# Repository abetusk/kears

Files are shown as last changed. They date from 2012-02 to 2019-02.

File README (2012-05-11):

Must have m4 installed, must have avr-as, avr-ld, avr-objcopy and avrdude.
ATTiny13 programed with ladyada's USBTinyISP (http://www.ladyada.net/make/usbtinyisp/)

To compile kears.asm:

./cmp.sh kears.asm

To program:

./program_avr.sh kears.ihex

If you have any comments or questions, send email to 'abetusk' at 'gmail' dot 'com'.

kears.asm should be functioning now, though I still need to play around
with the different PWM lengths for each state.  I would also like
to play around with adding more states (the "distracted" states)
so that's to be added.

The 'cmp.sh' script is doing the following:
m4 demo.S > demo.asm
avr-as -mmcu=attiny13 -o demo.o demo.asm
avr-ld -o demo.elf demo.o
avr-objcopy --output-target=ihex demo.elf demo.ihex
avrdude -c usbtiny -p t13 -U flash:w:demo.ihex

NOTES:

assumes attiny13 set to internal oscillator at 9.6 MHz

fuse high bits (e.g. fuseh.hex):
:01000000FF00
:00000001FF

fuse low bits (e.g. fusel.hex):
:010000007A85
:00000001FF

to program fuses:
sudo avrdude -c usbtiny -p t13 -U lfuse:w:0x7a:m
sudo avrdude -c usbtiny -p t13 -U hfuse:w:0xff:m
I think...

a note on timing:
we're assuming the attiny13 has been set to an internal
oscillator of 9.6 MHz
we've set up the timer0 overflow to increment once per
clock cycle, which means it should overflow once 
every 256 instructions.
so, 9,600,000 instructions / second
256 instructions / fire
-> 37,500 timer0 fires / second

dammit, can never remember:
Mega  10^6
milli 10^{-3}
micro 10^{-6}

the hxt900 (http://www.servodatabase.com/servo/hextronik/hxt900),
or compatible, servo wants a 450-2450 \mu s (microsecond) 
pulse width with a 20 ms (millisecond) pulse cycle

so, if we wanted to set up a counter in the timer0 overflow
to be on for x microseconds and cycle every y milliseconds

x 10^{-6} = ( X fires ) / ( 37,500 fires / second )
-> X = x * 37,500 / 10^6
-> Y = y * 37,500 / 10^3

for y = 20 milliseconds   -> Y     = 750      fires
for x = 450 microseconds  -> X_min = 16.875   fires
for x = 2450 microseconds -> X_max = 91.875   fires

and of course we have 8bit registers, so if we wanted
to count to 750, we need two registers with the
high bits being 2 and the low bits being 238
( ( 2*2^8 + 238 ) = 750 ).
This is where the values for HPW and LPW come from.
LLEFTC through RRIGHTC simarly come from choosing
values in the range of X_min and X_max.

I've chosen about DEBOUNCEH and DEBOUNCEL to be 
1/10th of a second (100 ms, what we generally 
believe to be 'instantaneous' as humans)
(14*256 + 166) = 3750 fires -> 1/10 second

I've chosen the button timer (how long you need
to press the button before it changes state)
to be .35 of a second.  I might want to decrease
this time a bit because it's noticeably slow.

NOTE (2):

The current working source is the 'kears.asm'.  
I originally programmed this in C but ran into 
size constraints with the ATtiny13 and had to 
switch over to assembly.  I have provided a 
previous version of the source, 'kears.c', in 
case anyone wants to play around with it or 
look at it.  The 'kears.c' should compile and 
work fine, just like the 'kears.asm', version, 
but without the extra 'wink' function (i.e. 
only two preset motions, the 'surprised' and 
'sad/angry' motions are available).

To compile kears.c:

fionna@Ooo:~$ ./cmp.sh

To program:

fionna@Ooo:~$ ./program_avr.sh kears.hex

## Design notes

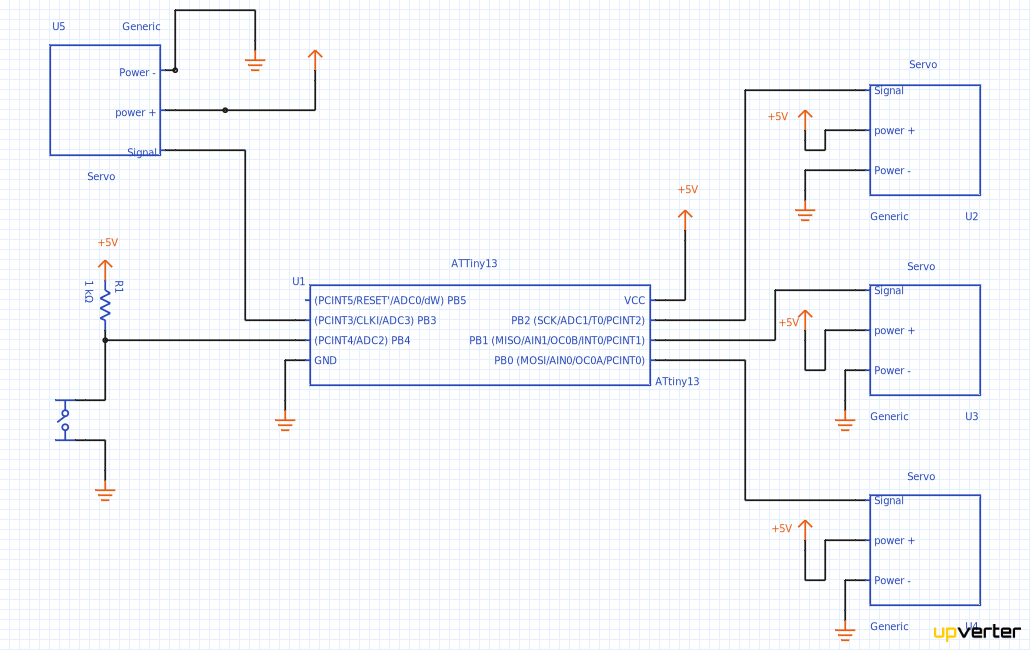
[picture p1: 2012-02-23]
Kears.png

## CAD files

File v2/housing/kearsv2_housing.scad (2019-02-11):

// kears v2 electronic housing
//
// Licensed under CC0
//

MAIN_BOARD_HOLE_DH = 89;
MAIN_BOARD_HOLE_DW = 38;

PWM_HOLE_DH = 56;
PWM_HOLE_DW = 18;

SWITCH_HOLE_DS = 20;

JOYSTICK_HOLE_DH = 19;
JOYSTICK_HOLE_DW = 24;

TUBE_R = 30;
TUBE_RECT_W = 2*tan(22.5)*TUBE_R;

MATERIAL_THICKNESS = 3;
SLOT_W = TUBE_RECT_W - 6;
SLOT_H = MATERIAL_THICKNESS;

SCREW_R = 2/2;

FN=32;

module hexagon(r) {
  dh = 2*r;
  dw = 2*tan(22.5)*r;
  union() {
    square([dh,dw], center=true);
    rotate(45, [0,0,1]) square([dh,dw], center=true);
    rotate(90, [0,0,1]) square([dh,dw], center=true);
    rotate(-45, [0,0,1]) square([dh,dw], center=true);
  };
}

module head_plate() {
  m = MATERIAL_THICKNESS;
  difference() {
    
    hexagon(TUBE_R);
    
    translate([0, TUBE_R - m*2])
      square([SLOT_W, SLOT_H], center=true);
    translate([0, -(TUBE_R - m*2)])
      square([SLOT_W, SLOT_H], center=true);
    
    translate([TUBE_RECT_W/2 + m, 0])
      square([SLOT_H, SLOT_W], center=true);
    translate([-(TUBE_RECT_W/2 + m), 0])
      square([SLOT_H, SLOT_W], center=true);

    translate([-(TUBE_R-1.5*SLOT_H),0])
      square([SLOT_H, SLOT_W], center=true);
    translate([ (TUBE_R-1.5*SLOT_H),0])
      square([SLOT_H, SLOT_W], center=true);
    
    translate([0,TUBE_R/4]) circle(TUBE_R/3, $fn=FN);
  };
}

module back_plate() {
  m = MATERIAL_THICKNESS;
  difference() {
    
    hexagon(TUBE_R);
    
    translate([0, TUBE_R - m*2])
      square([SLOT_W, SLOT_H], center=true);
    translate([0, -(TUBE_R - m*2)])
      square([SLOT_W, SLOT_H], center=true);
    
    translate([TUBE_RECT_W/2 + m, 0])
      square([SLOT_H, SLOT_W], center=true);
    translate([-(TUBE_RECT_W/2 + m), 0])
      square([SLOT_H, SLOT_W], center=true);

    translate([-(TUBE_R-1.5*SLOT_H),0])
      square([SLOT_H, SLOT_W], center=true);
    translate([ (TUBE_R-1.5*SLOT_H),0])
      square([SLOT_H, SLOT_W], center=true);

    square([10,6], center=true);

  };
}

module side_inner_plate() {
  dh = TUBE_R*2 - 2*MATERIAL_THICKNESS;
  dl = MAIN_BOARD_HOLE_DH + 4*MATERIAL_THICKNESS;
  m = MATERIAL_THICKNESS;
  
  cut_l = MAIN_BOARD_HOLE_DH - 4*m;
  cut_h = MAIN_BOARD_HOLE_DW - 4*m;
  
  h_l = MAIN_BOARD_HOLE_DH;
  h_h = MAIN_BOARD_HOLE_DW;
  
  difference() {
    union() {
      square([dl,dh], center=true);
      translate([dl/2 + SLOT_H/2,0])
        square([SLOT_H, SLOT_W], center=true);
      translate([-(dl/2 + SLOT_H/2),0])
        square([SLOT_H, SLOT_W], center=true);
    };
    
    translate([0,dh/2-m-SLOT_H/2])
      square([SLOT_W, SLOT_H],center=true);
    translate([0,-(dh/2-m-SLOT_H/2)])
      square([SLOT_W, SLOT_H],center=true);
    
    hull() {
      translate([-cut_l/2, -cut_h/2])
        circle(m);
      translate([ cut_l/2, -cut_h/2])
        circle(m);
      translate([ cut_l/2,  cut_h/2])
        circle(m);
      translate([-cut_l/2,  cut_h/2])
        circle(m);
    };
    
    translate([-h_l/2, -h_h/2])
      circle(SCREW_R, $fn=FN);
    translate([ h_l/2, -h_h/2])
      circle(SCREW_R, $fn=FN);
    translate([ h_l/2,  h_h/2])
      circle(SCREW_R, $fn=FN);
    translate([-h_l/2,  h_h/2])
      circle(SCREW_R, $fn=FN);

  };
}

module side_inner_plate_1() {
  dh = TUBE_R*2 - 2*MATERIAL_THICKNESS;
  dl = MAIN_BOARD_HOLE_DH + 4*MATERIAL_THICKNESS;
  m = MATERIAL_THICKNESS;
  
  cut_l = PWM_HOLE_DH - 4*m;
  cut_h = PWM_HOLE_DW - 4*m;
  
  h_l = PWM_HOLE_DH;
  h_h = PWM_HOLE_DW;
  

  difference() {
    union() {
      square([dl,dh], center=true);
      translate([dl/2 + SLOT_H/2,0])
        square([SLOT_H, SLOT_W], center=true);
      translate([-(dl/2 + SLOT_H/2),0])
        square([SLOT_H, SLOT_W], center=true);
    };
    
    translate([0,dh/2-m-SLOT_H/2])
      square([SLOT_W, SLOT_H],center=true);
    translate([0,-(dh/2-m-SLOT_H/2)])
      square([SLOT_W, SLOT_H],center=true);
    
    hull() {
      translate([-cut_l/2, -cut_h/2])
        circle(m);
      translate([ cut_l/2, -cut_h/2])
        circle(m);
      translate([ cut_l/2,  cut_h/2])
        circle(m);
      translate([-cut_l/2,  cut_h/2])
        circle(m);
    };
    
    translate([-h_l/2, -h_h/2])
      circle(SCREW_R, $fn=FN);
    translate([ h_l/2, -h_h/2])
      circle(SCREW_R, $fn=FN);
    translate([ h_l/2,  h_h/2])
      circle(SCREW_R, $fn=FN);
    translate([-h_l/2,  h_h/2])
      circle(SCREW_R, $fn=FN);

  };
}

module action_plate() {
  m = MATERIAL_THICKNESS;
  dw = 50;
  dh = 40;
  
  bx = -12;
  by = 0;
  bw = 4*SCREW_R;
  bh = SWITCH_HOLE_DS - 4*SCREW_R;
  
  jsx = 5;
  jsy = 0;
  jsr = JOYSTICK_HOLE_DH/2 - m;
  js_dh = JOYSTICK_HOLE_DH;
  js_dw = JOYSTICK_HOLE_DW;
  difference() {
    square([dw, dh], center=true);
    
    translate([-(dw/2-m-SLOT_H/2),0])
      square([SLOT_H,SLOT_W], center=true);
    translate([ (dw/2-m-SLOT_H/2),0])
      square([SLOT_H,SLOT_W], center=true);

    
    translate([bx,by])
      square([bw,bh], center=true);
    translate([bx,by + SWITCH_HOLE_DS/2])
      circle(SCREW_R, $fn=FN);
    translate([bx,by - SWITCH_HOLE_DS/2])
      circle(SCREW_R, $fn=FN);

    hull() {
      translate([jsx, jsy])
        circle(jsr, $fn=FN);
      translate([jsx, jsy- 20])
        circle(jsr, $fn=FN);
    };
    translate([jsx - js_dh/2,jsy - js_dw/2])
      circle(SCREW_R, $fn=FN);
    translate([jsx + js_dh/2,jsy - js_dw/2])
      circle(SCREW_R, $fn=FN);
    translate([jsx + js_dh/2,jsy + js_dw/2])
      circle(SCREW_R, $fn=FN);
    translate([jsx - js_dh/2,jsy + js_dw/2])
      circle(SCREW_R, $fn=FN);
  };
}

head_plate();
translate([2*TUBE_R + 5,0]) back_plate();
translate([-100,0]) side_inner_plate();
translate([-100,60]) side_inner_plate_1();
translate([160,0]) side_inner_plate_1();

translate([0,60]) action_plate();

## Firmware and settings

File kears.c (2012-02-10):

#include <avr/interrupt.h>

#define DEBOUNCEH 14
#define DEBOUNCEL 166

#define HPW 2
#define LPW 238

#define LLEFTC 20
#define LEFTC 35
#define MIDC 55
#define RIGHTC 80
#define RRIGHTC 95

#define POS_LEFT 1
#define POS_MID 2
#define POS_RIGHT 3
#define POS_L_LEFT 4
#define POS_R_RIGHT 5

#define BUTTON_PRESS1 2
#define BUTTON_HOLD1 3
#define BUTTON_RELEASE1 4
#define BUTTON_PRESS2 5
#define BUTTON_HOLD2 6
#define BUTTON_RELEASE2 7
#define BUTTON_PRESS3 8
#define BUTTON_HOLD3 9
#define BUTTON_RELEASE3 10

#define BUTTON_AUX_STATE1 11
#define BUTTON_AUX_STATE2 12
#define BUTTON_AUX_STATE3 13
#define BUTTON_AUX_STATE4 14

#define BUTTON_START 15

#define TIME_BUTTON_H 50
#define TIME_BUTTON_L 255

#define EAR_STATE_IDLE 1
#define EAR_STATE_SURPRISE 2
#define EAR_STATE_ANGRY 3
#define EAR_STATE_DISTRACTED_1 4
#define EAR_STATE_DISTRACTED_2 5
#define EAR_STATE_DISTRACTED_3 6
#define EAR_STATE_DISTRACTED_4 7

// button state counter

volatile unsigned char button_state=BUTTON_START;
volatile unsigned char button_h=0;
volatile unsigned char button_l=0;

unsigned char ear_state=EAR_STATE_IDLE;

// button debounce counter
volatile char hbc=0;
volatile char lbc=0;
volatile char button=0;

// pwm counter
volatile char hcounter=0;
volatile char lcounter=0;

//motor position variables
volatile unsigned char state0=POS_LEFT;
volatile unsigned char state1=POS_LEFT;
volatile unsigned char state2=POS_LEFT;
volatile unsigned char state3=POS_LEFT;

void moto_func(unsigned char state, unsigned char PBX) {

  if (state==POS_LEFT) {
    if ((hcounter==0) && (lcounter == LEFTC)) {
      PORTB &= ~(1<<PBX);
    }
  } else if (state==POS_MID) {
    if ((hcounter==0) && (lcounter == MIDC)) {
      PORTB &= ~(1<<PBX);
    }
  } else if (state==POS_RIGHT) {
    if ((hcounter==0) && (lcounter == RIGHTC)) {
      PORTB &= ~(1<<PBX);
    }
  } else if (state==POS_L_LEFT) {
    if ((hcounter==0) && (lcounter == LLEFTC)) {
      PORTB &= ~(1<<PBX);
    }
  } else if (state==POS_R_RIGHT) {
    if ((hcounter==0) && (lcounter == RRIGHTC)) {
      PORTB &= ~(1<<PBX);
    }
  }

}

#define button_transition(x) button_h = TIME_BUTTON_H ; button_l = TIME_BUTTON_L ; button_state = (x)

// called 37500 a second
ISR(TIM0_OVF_vect) {

  if ((button_h != 0) || (button_l != 0)) {
    if (button_l == 0) {
      if (button_h>0) {
        button_l = 255;
        button_h--;
      }
    } else {
      button_l--;
    }
  }

  // PWM servo motor control

  lcounter++;
  if (lcounter==0) hcounter++;

  if ((hcounter==HPW) && (lcounter==LPW)) {
    lcounter=hcounter=0;
    PORTB |=  (1<<PB3) | (1<<PB2) | (1<<PB1) | (1<<PB0);
  }


  moto_func(state1, PB3);
  moto_func(state2, PB2);
  moto_func(state3, PB1);
  moto_func(state0, PB0);


  button=0;
  if ( PINB & (1<<PB4) ) {
    hbc=lbc=0;
  } else {
    lbc++;
    if (lbc==0) hbc++;
    if ( (hbc >= DEBOUNCEH) && (lbc >= DEBOUNCEL)) {
      button=1;
      hbc=DEBOUNCEH;
      lbc=DEBOUNCEL;
    }
  }


}

                
int main(void) {
  char t;


  DDRB = 0b00001111;

  // prescale timer to every clock tick
  TCCR0B |= (0<<CS02) | (0<<CS01) | (1<<CS00);
                                
  // enable timer overflow interrupt
  TIMSK0 |=1<<TOIE0;
  sei();
                                          
  while(1) {

    /*
    if (button) {
      ear_state = EAR_STATE_ANGRY;
    } else {
      ear_state = EAR_STATE_IDLE;
    }
    */


    // button state control

    if (button_state == BUTTON_START) {
      ear_state=EAR_STATE_IDLE;
      if (button) {
        button_transition(BUTTON_PRESS1);
      }
    } 
    else if (button_state == BUTTON_PRESS1) {
      if ((button_h==0) && (button_l==0)) {
        button_state = BUTTON_HOLD1;
      }
      else if (button==0) {
        button_transition(BUTTON_RELEASE1);
      }
    }
    else if (button_state == BUTTON_HOLD1) {
      ear_state=EAR_STATE_SURPRISE;
      if (button==0) {
        button_state = BUTTON_START;
      }
    }
    else if (button_state == BUTTON_RELEASE1) {
      if (button) {
        button_transition(BUTTON_PRESS2);
      }
      if ((button_h==0) && (button_l==0)) {
        button_state = BUTTON_START;
      }
    }

    else if (button_state == BUTTON_PRESS2) {
      if ((button_h==0) && (button_l==0)) {
        button_state = BUTTON_HOLD2;
      }
      else if (button==0) {
        button_transition(BUTTON_RELEASE2);
      }
    }
    else if (button_state == BUTTON_HOLD2) {
      ear_state=EAR_STATE_ANGRY;
      if (button==0) {
        button_state = BUTTON_START;
      }
    } 
    else if (button_state == BUTTON_RELEASE2) {

      //if (button) {
      //  button_transition(BUTTON_AUX_STATE1);
      //}
      button_state = BUTTON_START;
    }

//    else {
//      char t = ear_state-BUTTON_AUX_STATE1;
//      ear_state = EAR_STATE_DISTRACTED_1 + t;
//      if ( (button_h == 0) && (button_l == 0)) {
//        button_transition(BUTTON_AUX_STATE2+t);
//      }
//      if (button_state>=BUTTON_START) button_state=BUTTON_START;
//    } 


    // logical ear state control

    if (ear_state == EAR_STATE_IDLE) {
      state0=POS_LEFT;
      state1=POS_RIGHT;
      state2=POS_RIGHT;
      state3=POS_LEFT;
    } else if (ear_state == EAR_STATE_SURPRISE) {
      state0=POS_LEFT;
      state1=POS_R_RIGHT;
      state2=POS_RIGHT;
      state3=POS_L_LEFT;
    } else if (ear_state == EAR_STATE_ANGRY) {
      state0=POS_RIGHT;
      state1=POS_LEFT;
      state2=POS_LEFT;
      state3=POS_RIGHT;
    } else if ((ear_state == EAR_STATE_DISTRACTED_1) ||
               (ear_state == EAR_STATE_DISTRACTED_3)) {
      state0=POS_LEFT;
      state1=POS_LEFT;
      state2=POS_RIGHT;
      state3=POS_MID;
    } else if ((ear_state == EAR_STATE_DISTRACTED_2) ||
               (ear_state == EAR_STATE_DISTRACTED_4)) {
      state0=POS_RIGHT;
      state1=POS_RIGHT;
      state2=POS_RIGHT;
      state3=POS_MID;
    }


  }

}

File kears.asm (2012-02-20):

;    This program is free software: you can redistribute it and/or modify
;    it under the terms of the GNU General Public License as published by
;    the Free Software Foundation, either version 3 of the License, or
;    (at your option) any later version.
;
;    This program is distributed in the hope that it will be useful,
;    but WITHOUT ANY WARRANTY; without even the implied warranty of
;    MERCHANTABILITY or FITNESS FOR A PARTICULAR PURPOSE.  See the
;    GNU General Public License for more details.
;
;    You should have received a copy of the GNU General Public License
;    along with this program.  If not, see <http://www.gnu.org/licenses/>.
;
; to compile and load:
; m4 demo.S > demo.asm
; avr-as -mmcu=attiny13 -o demo.o demo.asm
; avr-ld -o demo.elf demo.o
; avr-objcopy --output-target=ihex demo.elf demo.ihex
; avrdude -c usbtiny -p t13 -U flash:w:demo.ihex
;


.include "kears_equ.S"

define(brz, breq)
define(brnz, brne)
define(bron, brne)

define(zero, r8)

define(button_h, r10)
define(button_l, r11)

define(aux_counter_l, r12)
define(aux_counter_h, r13)

define(aux_pos, r15)

define(button_state, r16)

define(tmp, r17)
define(t, r18)


define(ear_state, r19)
define(hbc, r20)
define(lbc, r21)
define(button, r22)

define(hcounter, r23)
define(lcounter, r24)

; NOTE, output port mapping to motors is:
; 0 bottom right
; 1 bottom left
; 2 up left
; 3 up right
define(moto_pwm_state0, r25)
define(moto_pwm_state1, r26)
define(moto_pwm_state2, r27)
define(moto_pwm_state3, r28)


define(zh, r31)
define(zl, r30)

.equ SREG, 0x3f
.equ TIMSK0, 0x39
.equ TCCR0B, 0x33
.equ PORTB,0x18
.equ DDRB ,0x17
.equ PINB, 0x16

;;;;;;;;;;;;;;;;;;;;;;;;;;;;;;;;;;;;
;;; sets up buttn timer for debounce
;;; and changes state
.macro butt_trans x
  cli
  ldi   t, TIME_BUTTON_H
  mov   button_h, t
  ldi   t, TIME_BUTTON_L
  mov   button_l, t
  ldi   button_state, \x
  sei
.endm

;;;;;;;;;;;;;;;;;;;;;;;;;;;;;;;;;;;;;;;;;;
;;;; set up aux timer and transition state
.macro aux_trans x
  cli
  ldi   t, AUX_COUNTER_H
  mov   aux_counter_h, t
  ldi   t, AUX_COUNTER_L
  mov   aux_counter_l, t
  ldi   button_state, \x
  sei
.endm

;;;;;;;;;;;;;;;;;;;;;;;;;;;;;;;;;;;;
;;;; test aux counter for expiration
.macro aux_n_exp skip_label  ; aux not expired, go to skip_label
  tst   aux_counter_h
  brnz  \skip_label
  tst   aux_counter_l
  brnz  \skip_label
.endm

;;;;;;;;;;;;;;;;;;;;;;
;;; set up aux counter
.macro set_aux_cnt
  cli
  ldi   t, AUX_COUNTER_H
  mov   aux_counter_h, t
  ldi   t, AUX_COUNTER_L
  mov   aux_counter_l, t
  sei
.endm

.macro  set_ear_state a, b, c, d
  cli
  ldi   moto_pwm_state0, \a
  ldi   moto_pwm_state1, \b
  ldi   moto_pwm_state2, \c
  ldi   moto_pwm_state3, \d
  sei
.endm

.macro no_btn_hld skip_label
  tst   button_h
  brnz  \skip_label
  tst   button_l
  brnz  \skip_label
.endm

.macro moto_func state, ppos
  cp    lcounter, \state
  brne  moto_func_end_macro_\state
  cbi   PORTB, \ppos
moto_func_end_macro_\state:
.endm


.org 0x00
reset:
rjmp main        ; reset
rjmp defaultInt  ; ext_int0
rjmp defaultInt  ; pcint0
rjmp tim0_ovf    ; tim0_ovf
rjmp defaultInt  ; ee_rdy
rjmp defaultInt  ; ana_comp
rjmp defaultInt  ; tim0_compa
rjmp defaultInt  ; tim0_compb
rjmp defaultInt  ; watchdog
rjmp defaultInt  ; adc

defaultInt:
reti

;;;;; TIMER0 ON OVERFLOW
tim0_ovf:

  ;;;;;;;;;;;;;;
  ;;; save state
  ;;; 3
    push  tmp
    in    tmp, SREG
    push  tmp

  ;;;;;;;;;;;;;;;;;;;;
  ;;;;; button counter
  ;;; 4-6
    tst   button_l
    brnz  button_counter_dec_l
    tst   button_h
;    breq  button_counter_end
    brz   button_counter_end
    dec   button_h
  button_counter_dec_l:
    dec   button_l
  button_counter_end:

  ;;;;;;;;;;;;;;;;;;;;;;;;
  ;;;;; incrememnt counter
  ;;; 3
    inc   lcounter
    brne  skip_hcounter_incr
    inc   hcounter
  skip_hcounter_incr:


  ;;;;;;;;;;;;;;;;;;;;;;;;;;;;;;;;;;;;;;
  ;;;;; reset counter and set portb high
  ;;; 9
    cpi   hcounter, HPW
    brne  skip_set_moto
    cpi   lcounter, LPW
    brne  skip_set_moto
    ldi   hcounter, 0
    ldi   lcounter, 0

    in    tmp, PORTB
    ori   tmp, 0x0f
    out   PORTB, tmp

  skip_set_moto:

  ;;;;;;;;;;;;;;;;;;;;;
  ;;;;; motor functions
  ;;; 6 + 44
    tst  hcounter
    brnz moto_func_end

    moto_func moto_pwm_state0, 0 
    moto_func moto_pwm_state1, 1
    moto_func moto_pwm_state2, 2 
    moto_func moto_pwm_state3, 3 

  moto_func_end:

  ;;;;;;;;;;;;;;;;;;;;
  ;;;;; debounce logic
  ;;; 8-15
    ldi   button, 0
    in    tmp, PINB
    andi  tmp, 0x10  ; 1 << 4
    brz   debounce_reset_skip
    ldi   hbc, 0
    ldi   lbc, 0
    rjmp  debounce_end
  debounce_reset_skip:
    inc   lbc
    brnz  debounce_carry_skip
    inc   hbc
  debounce_carry_skip:
    cpi   hbc, DEBOUNCEH
    brlo  debounce_end
    cpi   lbc, DEBOUNCEL
    brlo  debounce_end 
    ldi   hbc, DEBOUNCEH
    ldi   lbc, DEBOUNCEL 
    ldi   button, 1
  debounce_end:


  ;;;;;;;;;;;;;;;;;
  ;;;;; aux counter
  ;;; 4-6
    tst   aux_counter_l
    brnz  aux_counter_dec_l
    tst   aux_counter_h
    brz   aux_counter_end
    dec   aux_counter_h
  aux_counter_dec_l:
    dec   aux_counter_l
  aux_counter_end:


  ;;;;;;;;;;;
  ;;; restore
  ;;; 3
    pop   tmp
    out   SREG, tmp
    pop   tmp

reti



;;;;;;;;;;;;;;
;;;;
;;;;/* MAIN */
;;;;
;;;;;;;;;;;;;;
main:

  ;;;;;;;;;;;;;;;;
  ;;;;;; init

  ; PB0-PB3 set as output, rest as input
  ldi   tmp, 0x0f
  out   DDRB, tmp

  ; no prescaling
  in    tmp, TCCR0B
  andi  tmp, 0xf8
  ori   tmp, 1
  out   TCCR0B, tmp

  ; enable timer interrupte
  in    tmp, TIMSK0
  ori   tmp, 2
  out   TIMSK0, tmp

  ; initialize global variables
  eor   zero, zero

  eor   hbc, hbc
  eor   lbc, lbc

  eor   button, button
  eor   button_h, button_h
  eor   button_l, button_l

  eor   hcounter, hcounter
  eor   lcounter, lcounter

  eor   aux_pos, aux_pos
  eor   aux_counter_h, aux_counter_h
  eor   aux_counter_l, aux_counter_l

  ldi   button_state, BUTTON_START

  ldi   ear_state, EAR_STATE_IDLE
  set_ear_state PWM_POS_c, PWM_POS_2, PWM_POS_4, PWM_POS_a

  eor   t, t
  eor   tmp, tmp

  sei

 
main_while:

;;;;;;;;;;;;;;;
;;;; ear states

  ldi   zh, pm_hi8(ear_state_jt)
  ldi   zl, pm_lo8(ear_state_jt)
  add   zl, ear_state
  adc   zh, zero
  ijmp

ear_state_jt:
  rjmp  ear_state_idle
  rjmp  ear_state_surprise
  rjmp  ear_state_angry
  rjmp  ear_state_distracted0
  rjmp  ear_state_distracted1
  rjmp  ear_state_distracted2
  rjmp  ear_state_distracted3
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

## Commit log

2012-02-10 added schematic
2012-02-23 Bug fix, U5 had power and ground reversed
